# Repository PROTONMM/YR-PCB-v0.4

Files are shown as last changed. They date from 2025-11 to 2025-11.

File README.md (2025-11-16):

# YoRadio – PCB (v0.4) for SSD1322 display

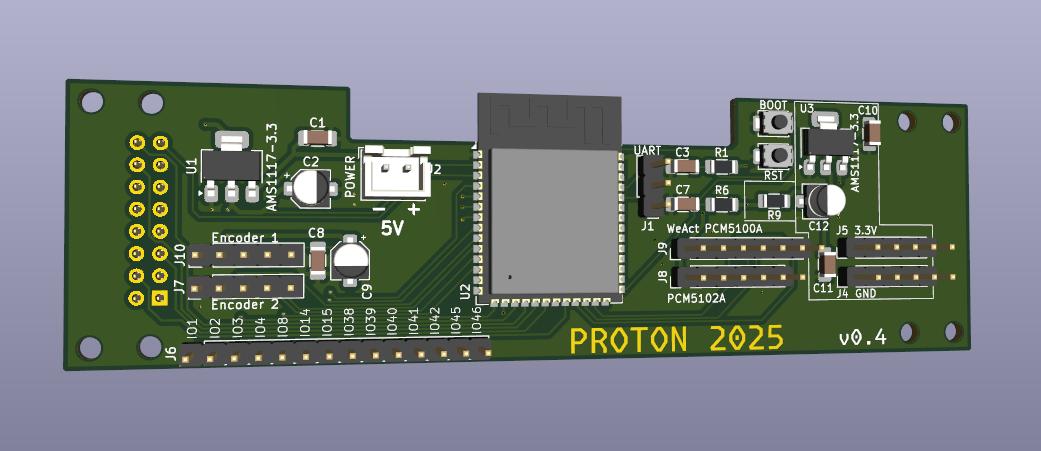
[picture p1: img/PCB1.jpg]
PCB – view 1

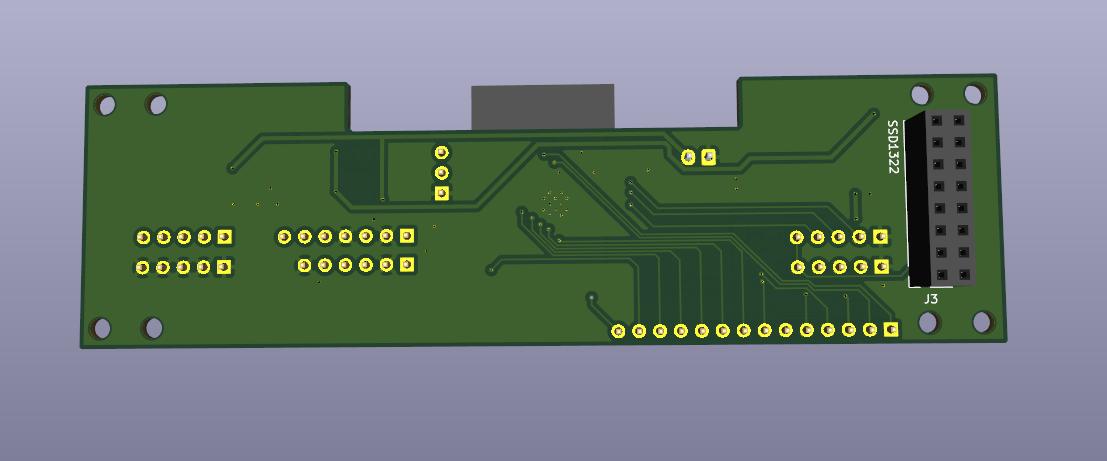
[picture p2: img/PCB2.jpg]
PCB – view 2


Hardware project of a printed circuit board (PCB) for YoRadio. The repository contains the complete KiCad project and ready-to-fabricate files (Gerbers + drill), as well as screenshots and board photos.

Status: stable v0.4 (fabrication files in the YR_v0.4 directory and the YR_v0.4.zip archive)

Note: Polish version available in README.pl.md

## Table of Contents
- Overview
- Repository contents
- Requirements and tools
- Quick start (KiCad)
- Fabrication files (Gerber/Drill)
- Assembly (BOM, stencil)
- Generating fabrication outputs
- Previews
- Versioning and backups
- License and disclaimers
- Contributing and issue reporting

## Overview

- Two-layer printed circuit board project for YoRadio.
- KiCad files allow editing the schematic and PCB and generating new fabrication outputs.
- The repository includes photos and screenshots of the project, as well as a Bill of Materials (BOM).

Note: The `myoptions_0.4.h` file is a firmware/software configuration header, included for convenience. It is not required to fabricate the PCB itself.

## Repository contents

Key files and directories:
- KiCad project:
  - `YR.kicad_pro` — KiCad project
  - `YR.kicad_sch` — schematic
  - `YR.kicad_pcb` — PCB layout
  - `schematic.pdf` — schematic in PDF format (view without KiCad)
- Fabrication (Gerber/Drill) — ready to send to the PCB manufacturer:
  - Directory: `YR_v0.4/`
  - Archive: `YR_v0.4.zip`
- Bill of Materials (BOM):
  - `YR.csv`
- Models/3D and graphics:
  - `YR.wrl` — 3D model (KiCad 3D Viewer)
  - `img/` — photos and screenshots (e.g., `PCB1.jpg`, `PCB2.jpg`)
- Project backups:
  - `YR-backups/` — automatic zip snapshots of the project

Other:
- `fp-info-cache` — footprint cache
- `YR.kicad_prl` — session/project settings
- `myoptions_0.4.h` — firmware configuration file (auxiliary)

## Requirements and tools

- KiCad 7/8 (latest stable release from series 7 or 8 recommended).
- To generate Gerber/Drill files: KiCad’s built-in tools (Plot/Generate Drill Files).
- Gerber viewer (e.g., KiCad’s built-in Gerber Viewer) — optional for verification.

## Quick start (KiCad)

1. Open the project: `YR.kicad_pro`.
2. Review the schematic: `YR.kicad_sch` (or `schematic.pdf` if you don’t have KiCad).
3. Open the PCB: `YR.kicad_pcb` (check layers and DRC rules).
4. 3D preview (optional): View → 3D Viewer (model `YR.wrl`).

## Fabrication files (Gerber/Drill)

Ready to send to the PCB manufacturer (version v0.4):
- Directory: `YR_v0.4/`
- Archive: `YR_v0.4.zip` (contains the same files, convenient to upload to the manufacturer)

Typical contents:
- Copper layers: `YR-F_Cu.gbr`, `YR-B_Cu.gbr`
- Solder masks: `YR-F_Mask.gbr`, `YR-B_Mask.gbr`
- Solder paste (stencil): `YR-F_Paste.gbr`, `YR-B_Paste.gbr` (if assembled on both sides)
- Silkscreen: `YR-F_Silkscreen.gbr`, `YR-B_Silkscreen.gbr`
- Board outline: `YR-Edge_Cuts.gbr`
- Drill files: `YR-PTH.drl`, `YR-NPTH.drl` (+ maps `*_drl_map.gbr`)
- Job file: `YR-job.gbrjob` (fabrication metadata from KiCad)

Recommended order parameters (typical, confirm with your manufacturer):
- Layer count: 2
- Material: FR4, 1.6 mm thickness (standard)
- Copper: 1 oz (35 µm)
- Solder mask: green (or other) + white silkscreen
- Finish: HAL Sn/Pb or lead-free HAL/ENIG per preference
- Minimum tracks/clearances/hole sizes: as per project DRC settings (check in KiCad)

## Assembly (BOM, stencil)

- BOM: `YR.csv` — parts list for procurement.
- Stencil: for SMD assembly, use the `*_Paste.gbr` files to manufacture a solder paste stencil.
- Note: ensure component orientations (diodes, electrolytics, ICs) match the polarity/orientation markers on the silkscreen.

## Programming the ESP32 Module

The ESP32 module is programmed using a USB–UART interface with a 3.3V logic level.
After connecting the interface and powering the board, press two buttons: RST and BOOT, then release them in the following order: first RST, then BOOT.
This will start the bootloader, which allows the module to be programmed directly from the Arduino IDE

## Generating fabrication outputs (from KiCad)

If you make changes and want to refresh the outputs:
1. PCB Editor → File → Plot…
   - Format: Gerber
   - Select layers: F_Cu, B_Cu, F_Mask, B_Mask, F_Paste, B_Paste, F_Silkscreen, B_Silkscreen, Edge.Cuts
   - Ensure the Plot format options meet your fab’s requirements (e.g., use vector font).
2. PCB Editor → File → Fabrication Outputs → Drill Files…
   - Generate `PTH.drl` and `NPTH.drl`.
3. Verify completeness and correctness in the Gerber Viewer (KiCad).
4. Zip the files and send them to your manufacturer.

## Previews

Sample photos and screenshots:
- `img/PCB1.jpg`
- `img/PCB2.jpg`
- `img/Screenshot_2025-11-09_18-42-12.png`
- `img/Screenshot_2025-11-09_18-42-12_mod.png`
- Real board photos: `img/20251109_183416.jpg`, `img/20251109_183430.jpg`, `img/20251109_183437.jpg`, `img/20251109_183449.jpg`

Example embeds:
PCB – view 1
PCB – view 2

## Versioning and backups

- Current version: v0.4 (directory `YR_v0.4/`, archive `YR_v0.4.zip`).
- Automatic backups: `YR-backups/` (with date and time).
- Recommendation: after significant changes, regenerate Gerber/Drill files and tag as a new version (e.g., v0.5).

## License and disclaimers

- License: there is no explicit license file in the repository — if you intend to share/use the project, choose and add a `LICENSE` (e.g., CERN-OHL, MIT, other).
- Disclaimer: the project is provided in good faith, without warranty. Use at your own risk; verify the design against your requirements and standards.

## Contributing and issue reporting

- Want to improve the project or add a feature? Open a Pull Request.
- Bugs/notes: create an Issue in the repository and include:
  - problem description,
  - project version (e.g., v0.4),
  - screenshots/photos or log files (if applicable).

Enjoy using the YoRadio PCB project!

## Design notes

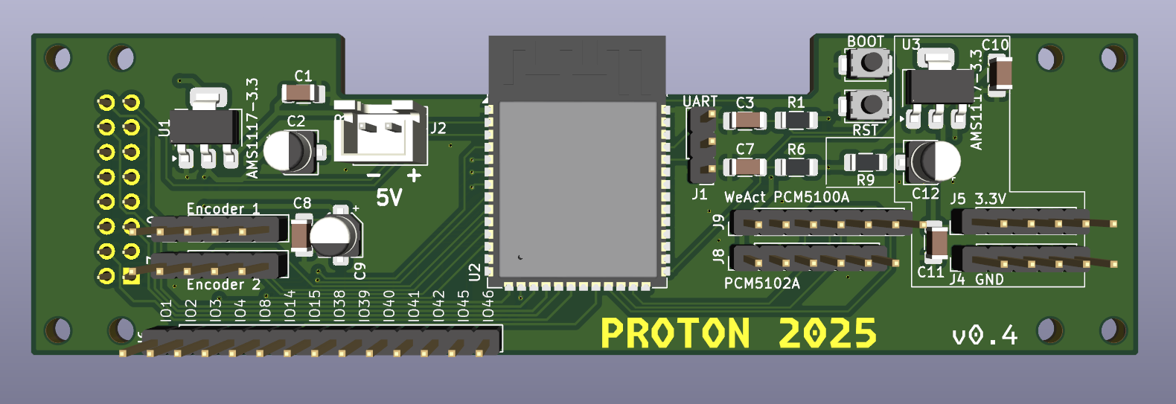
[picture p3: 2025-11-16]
img/Screenshot_2025-11-09_18-42-12.png

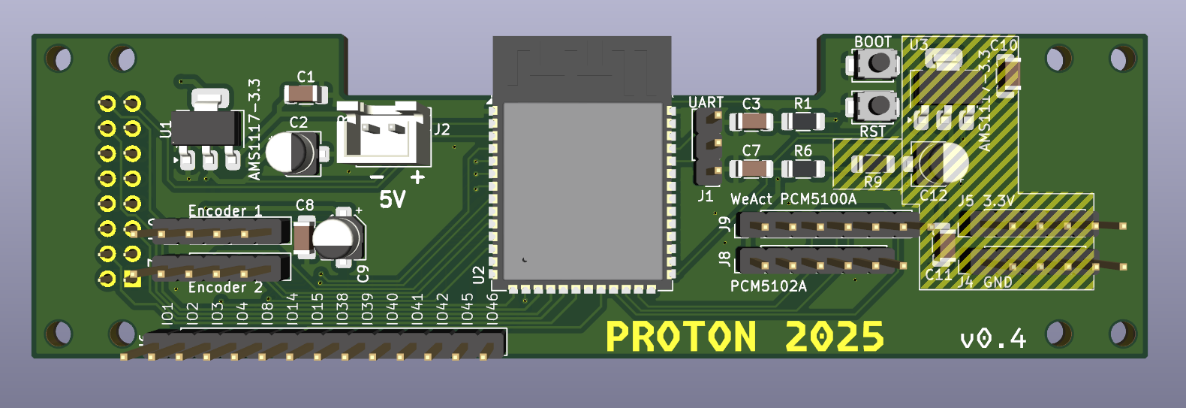
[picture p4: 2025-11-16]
img/Screenshot_2025-11-09_18-42-12_mod.png

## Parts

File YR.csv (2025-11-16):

Reference | Qty | Value | DNP | Exclude from BOM | Exclude from Board | Footprint | Datasheet
C1,C3,C7,C8,C10,C11 | 6 | 100n |  |  |  | Capacitor_SMD:C_1206_3216Metric_Pad1.33x1.80mm_HandSolder | ~
C2,C9,C12 | 3 | 10u |  |  |  | Capacitor_SMD:CP_Elec_4x3.9 | ~
J1 | 1 | UART |  |  |  | Connector_PinHeader_2.54mm:PinHeader_1x03_P2.54mm_Vertical | ~
J2 | 1 | POWER |  |  |  | Connector_JST:JST_XH_B2B-XH-A_1x02_P2.50mm_Vertical | ~
J3 | 1 | SSD1322 |  |  |  | Connector_PinSocket_2.54mm:PinSocket_2x08_P2.54mm_Vertical | ~
J4 | 1 | GND |  |  |  | Connector_PinHeader_2.54mm:PinHeader_1x05_P2.54mm_Vertical | ~
J5 | 1 | 3.3V |  |  |  | Connector_PinHeader_2.54mm:PinHeader_1x05_P2.54mm_Vertical | ~
J6 | 1 | GPIO |  |  |  | Connector_PinHeader_2.54mm:PinHeader_1x14_P2.54mm_Vertical | ~
J7 | 1 | Encoder 2 |  |  |  | Connector_PinHeader_2.54mm:PinHeader_1x05_P2.54mm_Vertical | ~
J8 | 1 | PCM5102A |  |  |  | Connector_PinHeader_2.54mm:PinHeader_1x06_P2.54mm_Vertical | ~
J9 | 1 | WeAct PCM5100A |  |  |  | Connector_PinHeader_2.54mm:PinHeader_1x07_P2.54mm_Vertical | ~
J10 | 1 | Encoder 1 |  |  |  | Connector_PinHeader_2.54mm:PinHeader_1x05_P2.54mm_Vertical | ~
R1,R6 | 2 | 10k |  |  |  | Resistor_SMD:R_1206_3216Metric_Pad1.30x1.75mm_HandSolder | ~
R9 | 1 | 10R |  |  |  | Resistor_SMD:R_1206_3216Metric_Pad1.30x1.75mm_HandSolder | ~
S1 | 1 | RST |  |  |  | Button_Switch_SMD:SW_SPST_TS-1088-xR025 | ~
S2 | 1 | BOOT |  |  |  | Button_Switch_SMD:SW_SPST_TS-1088-xR025 | ~
U1,U3 | 2 | AMS1117-3.3 |  |  |  | Package_TO_SOT_SMD:SOT-223-3_TabPin2 | http://www.advanced-monolithic.com/pdf/ds1117.pdf
U2 | 1 | ESP32-S3-WROOM-1 |  |  |  | RF_Module:ESP32-S3-WROOM-1 | https://www.espressif.com/sites/default/files/documentation/esp32-s3-wroom-1_wroom-1u_datasheet_en.pdf

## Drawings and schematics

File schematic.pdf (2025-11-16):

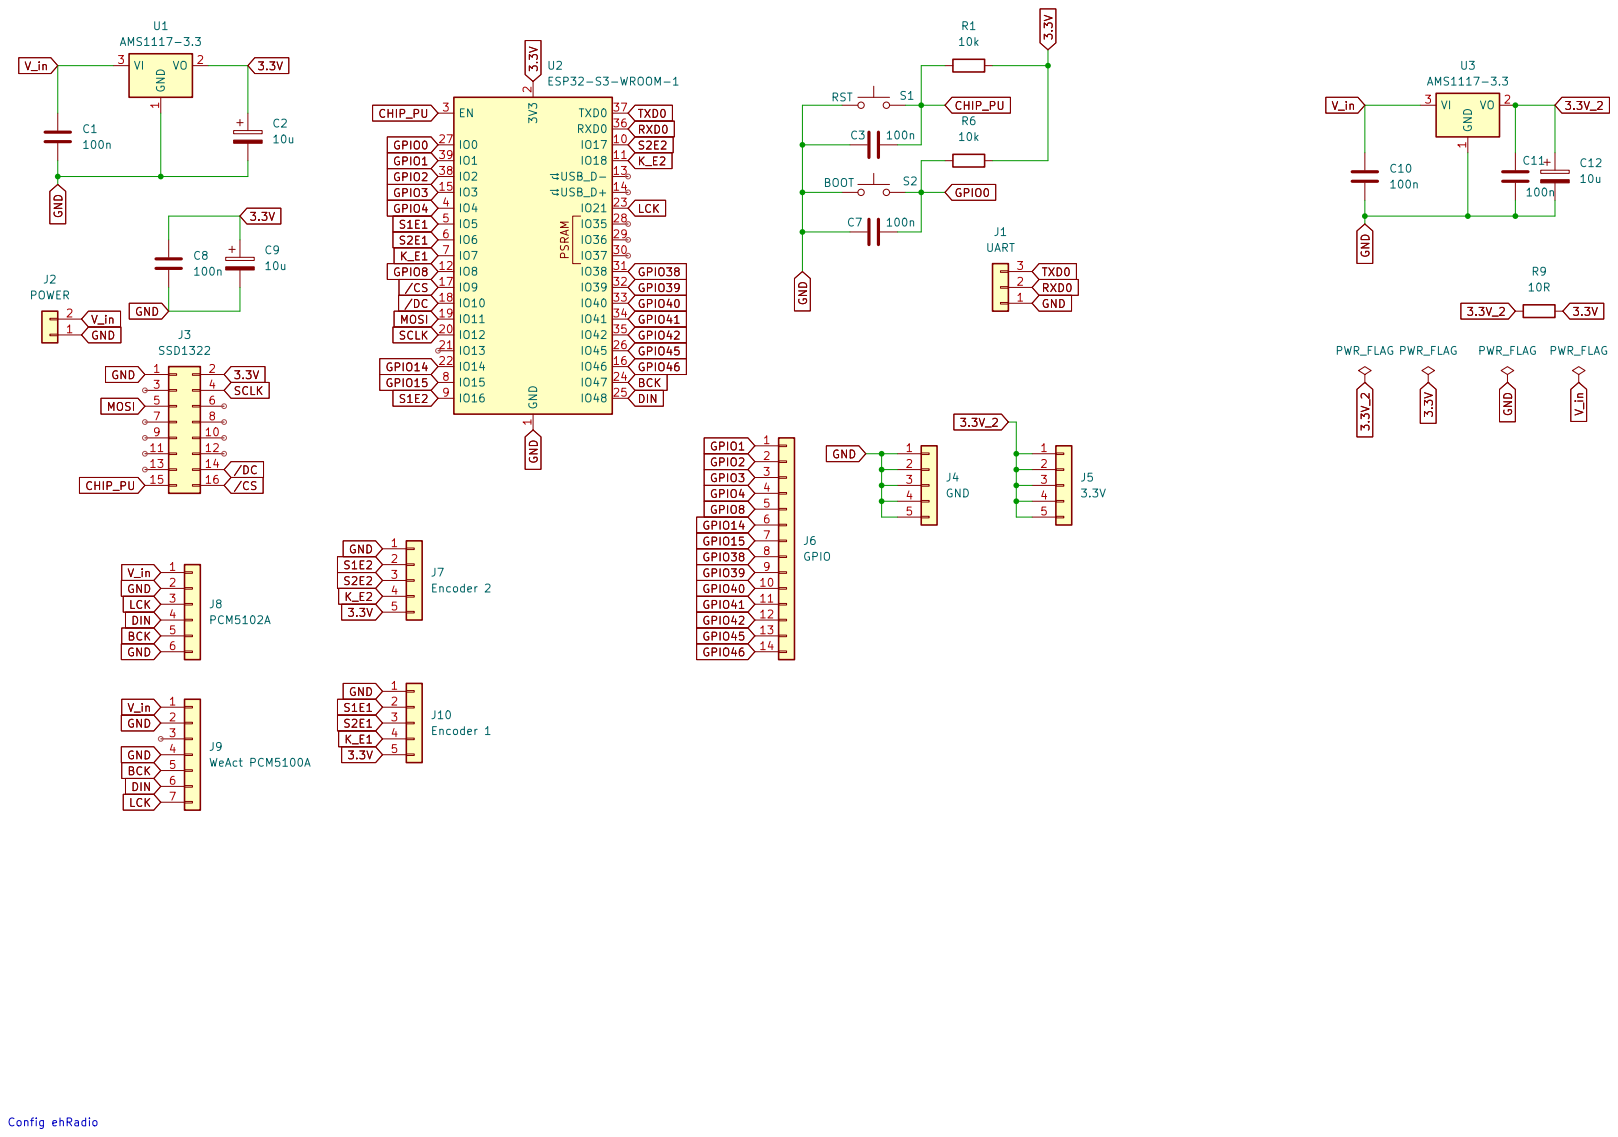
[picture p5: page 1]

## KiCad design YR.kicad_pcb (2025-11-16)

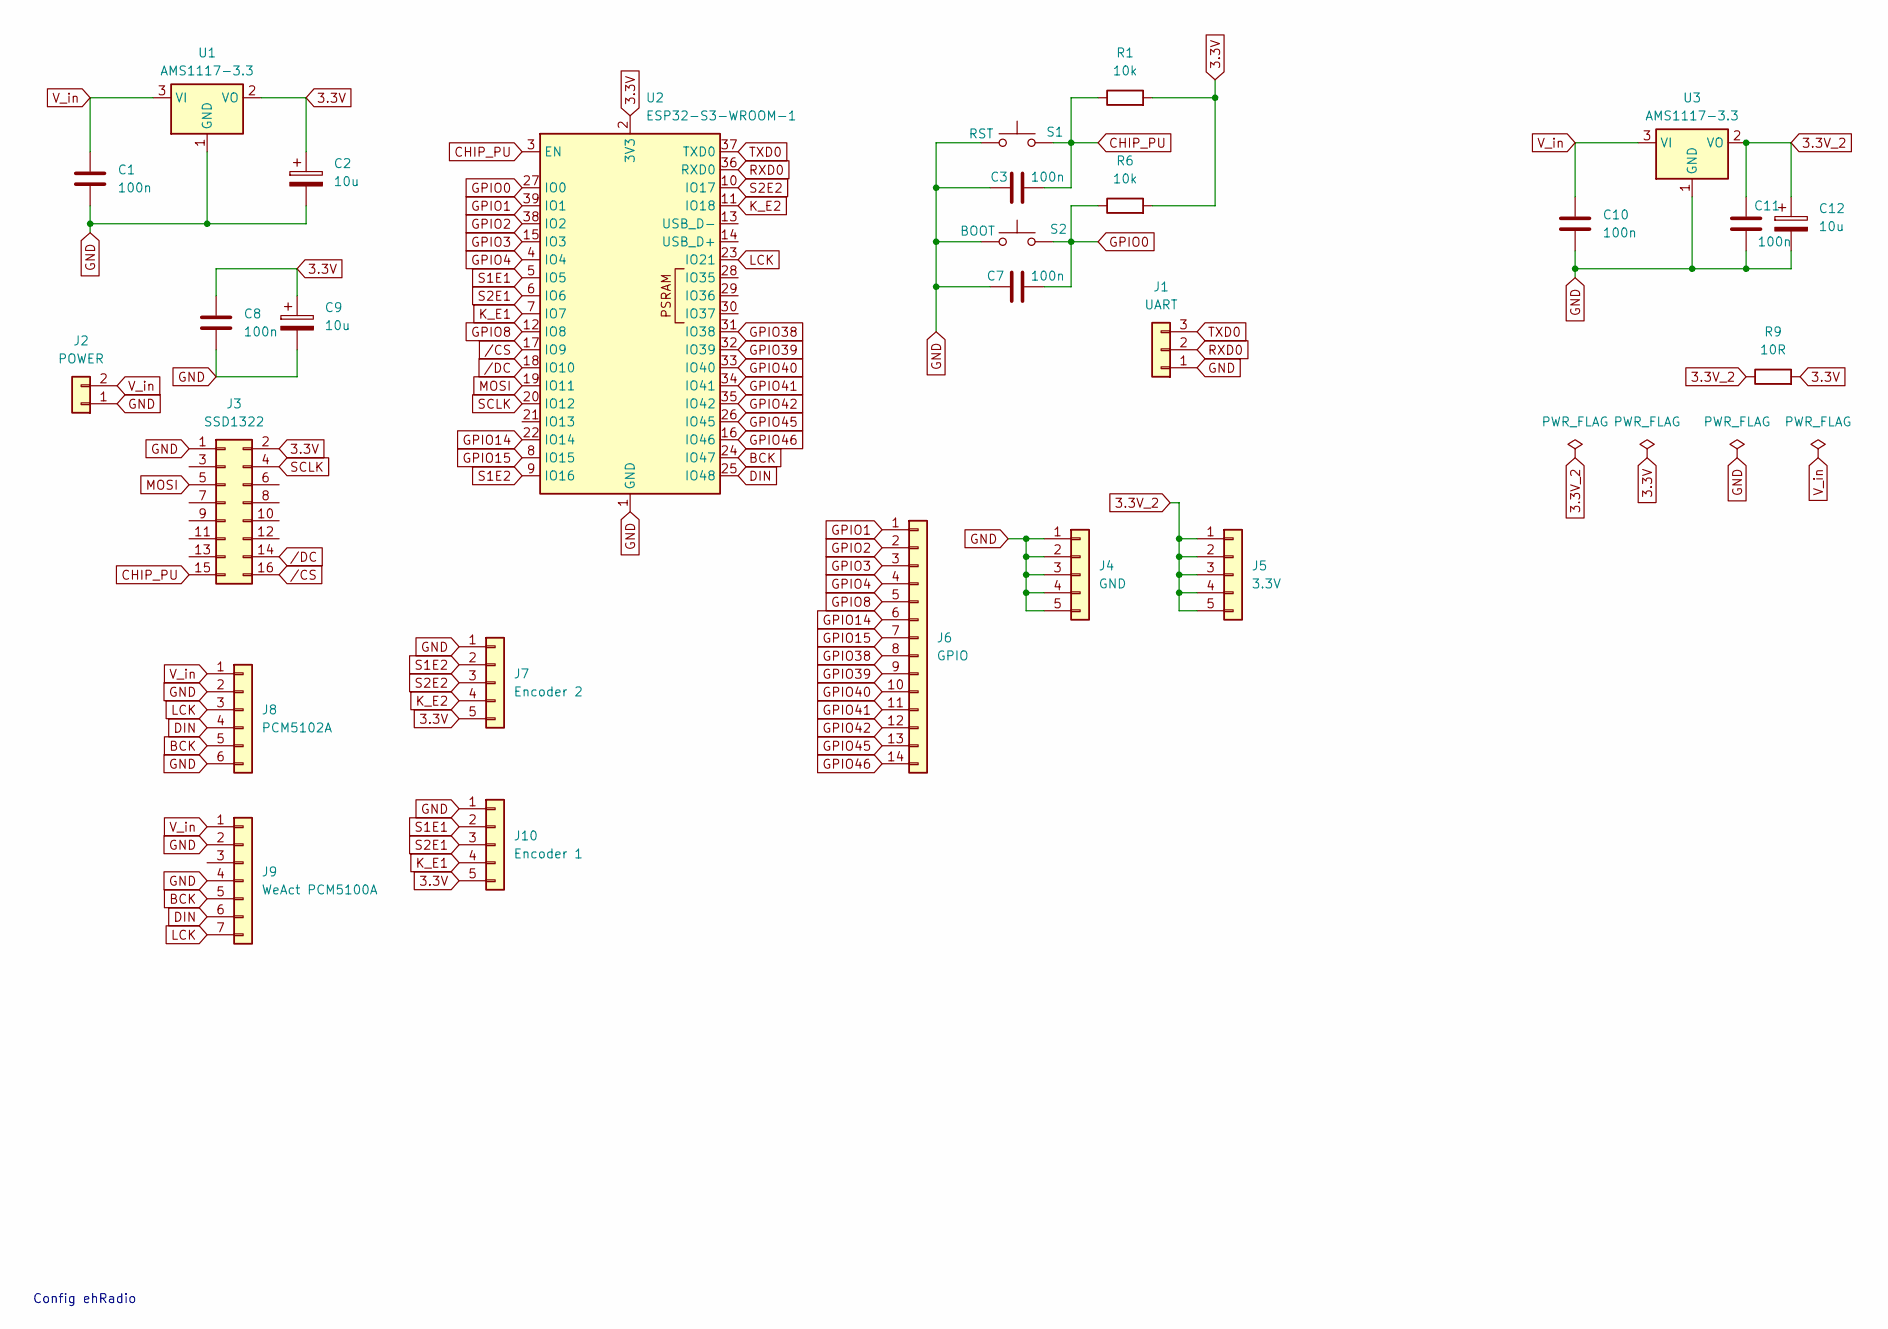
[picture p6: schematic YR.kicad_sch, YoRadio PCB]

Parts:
C1, C3, C7, C8, C10, C11: 100n; C_1206_3216Metric_Pad1.33x1.80mm_HandSolder
C2, C9, C12: 10u; CP_Elec_4x3.9
J1: UART; PinHeader_1x03_P2.54mm_Vertical
J2: POWER; JST_XH_B2B-XH-A_1x02_P2.50mm_Vertical
J3: SSD1322; PinSocket_2x08_P2.54mm_Vertical
J4: GND; PinHeader_1x05_P2.54mm_Vertical
J5: 3.3V; PinHeader_1x05_P2.54mm_Vertical
J6: GPIO; PinHeader_1x14_P2.54mm_Vertical
J7: Encoder 2; PinHeader_1x05_P2.54mm_Vertical
J8: PCM5102A; PinHeader_1x06_P2.54mm_Vertical
J9: WeAct PCM5100A; PinHeader_1x07_P2.54mm_Vertical
J10: Encoder 1; PinHeader_1x05_P2.54mm_Vertical
R1, R6: 10k; R_1206_3216Metric_Pad1.30x1.75mm_HandSolder
R9: 10R; R_1206_3216Metric_Pad1.30x1.75mm_HandSolder
S1: RST; SW_SPST_TS-1088-xR025
S2: BOOT; SW_SPST_TS-1088-xR025
U1, U3: AMS1117-3.3; SOT-223-3_TabPin2
U2: ESP32-S3-WROOM-1

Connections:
3.3V: C2.1, C8.1, C9.1, J3.2, J7.5, J10.5, R1.2, R6.2, R9.2, U1.2 (VO), U2.2 (3V3)
3.3V_2: C11.1, C12.1, J5.1, J5.2, J5.3, J5.4, J5.5, R9.1, U3.2 (VO)
BCK: J8.5, J9.5, U2.24 (IO47)
CHIP_PU: C3.2, J3.15, R1.1, S1.2, U2.3 (EN)
DIN: J8.4, J9.6, U2.25 (IO48)
GND: C1.2, C2.2, C3.1, C7.1, C8.2, C9.2, C10.2, C11.2, C12.2, J1.1, J2.1, J3.1, J4.1, J4.2, J4.3, J4.4, J4.5, J7.1, J8.2, J8.6, J9.2, J9.4, J10.1, S1.1, S2.1, U1.1 (GND), U2.1 (GND), U2.40 (GND), U2.41 (GND), U3.1 (GND)
GPIO0: C7.2, R6.1, S2.2, U2.27 (IO0)
GPIO1: J6.1, U2.39 (IO1)
GPIO2: J6.2, U2.38 (IO2)
GPIO3: J6.3, U2.15 (IO3)
GPIO4: J6.4, U2.4 (IO4)
GPIO8: J6.5, U2.12 (IO8)
GPIO14: J6.6, U2.22 (IO14)
GPIO15: J6.7, U2.8 (IO15)
GPIO38: J6.8, U2.31 (IO38)
GPIO39: J6.9, U2.32 (IO39)
GPIO40: J6.10, U2.33 (IO40)
GPIO41: J6.11, U2.34 (IO41)
GPIO42: J6.12, U2.35 (IO42)
GPIO45: J6.13, U2.26 (IO45)
GPIO46: J6.14, U2.16 (IO46)
K_E1: J10.4, U2.7 (IO7)
K_E2: J7.4, U2.11 (IO18)
LCK: J8.3, J9.7, U2.23 (IO21)
MOSI: J3.5, U2.19 (IO11)
RXD0: J1.2, U2.36 (RXD0)
S1E1: J10.2, U2.5 (IO5)
S1E2: J7.2, U2.9 (IO16)
S2E1: J10.3, U2.6 (IO6)
S2E2: J7.3, U2.10 (IO17)
SCLK: J3.4, U2.20 (IO12)
TXD0: J1.3, U2.37 (TXD0)
V_in: C1.1, C10.1, J2.2, J8.1, J9.1, U1.3 (VI), U3.3 (VI)
/CS: J3.16, U2.17 (IO9)
/DC: J3.14, U2.18 (IO10)

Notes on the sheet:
Config ehRadio

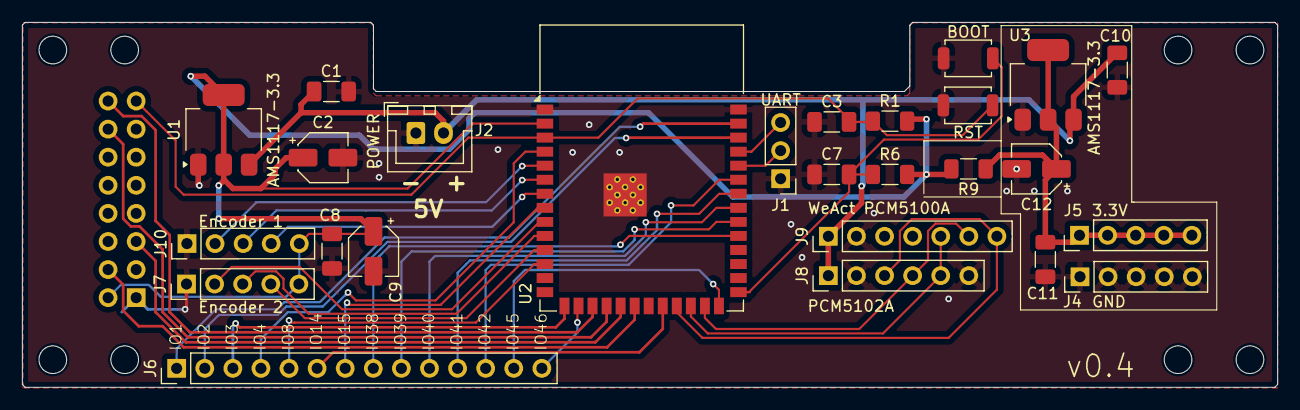
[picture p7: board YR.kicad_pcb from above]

Board: 2 copper layers, 113.5 x 33.0 mm, 27 parts (1 on the bottom side), 35 nets.

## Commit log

2025-11-16 YR PCB v0.4
    [YR-B_Cu.gbr, YR-B_Mask.gbr, YR-B_Paste.gbr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]
2025-11-16 add README and schematic
